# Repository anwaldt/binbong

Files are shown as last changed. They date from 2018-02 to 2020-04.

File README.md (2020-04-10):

# BinBong technical repository

## Overview

BingBong is a controller interface for the GLOOO Digital Music Instrument (DMI).
This repository contains all the necessary files to develop the firmaware for the controller and the receiving software patch for Pure Data.

## Requirements

### [Arduino IDE](https://www.arduino.cc/en/Main/Software)
  
- **Install through board manager**
  - [Redbear DUO Board package](https://github.com/redbear/Duo/blob/master/docs/arduino_board_package_installation_guide.md) 
    - **Important!** select version **0.3.1** when installing!

- **Install through library manager**
  -  Adafruit BNO055 library **1.1.9**
  -  Adafruit unified sensor library **1.0.3**
  -  Adafruit ADS1015 AD conversion library **1.0.0**
  -  AgileWare CircularBuffer **1.3.1**

- **Install manually**
  - Particle_osc (included in repo)
    - `cp /Arduino Libraries/particle_osc ${YOUR_ARDUINO_HOME}/libraries`

### [Pure Data (vanilla)](https://puredata.info/downloads)
  
- **Install through package manager inside PD** 
  - MrPeach

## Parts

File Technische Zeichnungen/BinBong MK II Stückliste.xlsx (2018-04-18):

BinBong MK II Stückliste
Part Name | Anzahl | Produkt verfügbar in/ auf |  | Verfügbar | Bemerkungen
Main Circuit
Main Circuit PCB | 1 | Lötlabor (http://www.loetlabor.org/Hauptseite) | or | 0
 |  | Beuth Hochschule (http://labor.beuth-hochschule.de/fvm/fertigung/leiterplatten-herstellung/)
RedBear Duo Microcontroller | 1 | https://www.exp-tech.de/plattformen/arm/stmicroelectronics/6995/redbear-duo-iot-board-mit-wifi-und-ble |  | 0
Force-Sesning Linear Potentiometer: 100mm x 10 mmStrip FSLP Sensor | 1 | https://www.exp-tech.de/sensoren/druck/7195/force-sensing-linear-potentiometer-100mm-x-10mm-strip-fslp-sensor |  | 0
Force-Sensing Resistor: 1.5cm-Diameter Circle, Short Tail FSR 402 Short | 4 | https://www.exp-tech.de/sensoren/druck/7198/force-sensing-resistor-1.5cm-diameter-circle-short-tail-fsr-402-short |  | 0
10 k Ohm Ceramic Resistors | 4 | Raum EN 111 |  | -
4.6 k Ohm Ceramic Resistor | 1 | Raum EN 111 |  | -
24 Ohm Ceramic Resistor | 1 | Raum EN 111 |  | -
Schraubklemmblock 0.82 mm² Polzahl 2 DG308-2.54-02P-14-00AH Degson Grün | 1 | https://www.conrad.de/de/schraubklemmblock-082-mm-polzahl-2-dg308-254-02p-14-00ah-degson-gruen-1-st-1327242.html |  | 8
Abstandshalter Polyamid Abstandsmaß 2.2 mm KSS MMS2 | 4 | https://www.conrad.de/de/abstandshalter-polyamid-abstandsmass-22-mm-kss-mms2-1-st-532152.html |  | 7
Female Pin Header Straight 12 Pol | 2 | https://www.conrad.de/de/buchsenleiste-praezision-anzahl-reihen-1-polzahl-je-reihe-36-w-p-products-153-036-1-50-10-1-st-736427.html |  | ca. 45 Pole
Female Pin Header Straight 4 Pol | 1 | https://www.conrad.de/de/buchsenleiste-praezision-anzahl-reihen-1-polzahl-je-reihe-36-w-p-products-153-036-1-50-10-1-st-736427.html |  | ca. 45 Pole
Female Pin Header Straight 3 Pol | 1 | https://www.conrad.de/de/buchsenleiste-praezision-anzahl-reihen-1-polzahl-je-reihe-36-w-p-products-153-036-1-50-10-1-st-736427.html |  | ca. 45 Pole
Female Pin Header 90° 3 Pol | 1 | https://www.conrad.de/de/buchsenleiste-praezision-anzahl-reihen-1-polzahl-je-reihe-40-w-p-products-154-040-1-50-00-1-st-739046.html |  | ca. 5 Pole
Female Pin Header 90° 8 Pol | 1 | https://www.conrad.de/de/buchsenleiste-praezision-anzahl-reihen-1-polzahl-je-reihe-40-w-p-products-154-040-1-50-00-1-st-739046.html |  | ca. 5 Pole
Sub-Circuit
Sub-Circuit PCB | 1 | Lötlabor (http://www.loetlabor.org/Hauptseite) | or | 4
 |  | Beuth Hochschule (http://labor.beuth-hochschule.de/fvm/fertigung/leiterplatten-herstellung/)
Round Force-Sensitive Resistor FSR 402 | 4 | https://www.exp-tech.de/sensoren/druck/5746/round-force-sensitive-resistor-fsr-402 |  | 3
Adafruit ADS1015 12-Bit ADC - 4 Channel with Progrmmable Gain Amplifier | 1 | https://www.exp-tech.de/module/sonstige/4579/adafruit-ads1015-12-bit-adc-4-channel-with-progrmmable-gain-amplifier |  | 2
Adafruit FLORA 9-DOF Accelerometer/ Gyroscope/ Magnetometer - LSM9DS0 | 1 | https://www.exp-tech.de/plattformen/plattformen/adafruit-flora/5835/adafruit-flora-9-dof-accelerometer/gyroscope/magnetometer-lsm9ds0 |  | 1
10 k Ohm Ceramic Resistors | 4 | Raum EN 111 |  | -
Abstandshalter Polyamid Abstandsmaß 2.2 mm KSS MMS2 | 4 | https://www.conrad.de/de/abstandshalter-polyamid-abstandsmass-22-mm-kss-mms2-1-st-532152.html |  | 7
Female Pin Header Straight 10 Pol | 1 | https://www.conrad.de/de/buchsenleiste-praezision-anzahl-reihen-1-polzahl-je-reihe-36-w-p-products-153-036-1-50-10-1-st-736427.html |  | ca. 45 Pole
Female Pin Header Straight 1 Pol | 4 | https://www.conrad.de/de/buchsenleiste-praezision-anzahl-reihen-1-polzahl-je-reihe-36-w-p-products-153-036-1-50-10-1-st-736427.html |  | ca. 45 Pole
Female Pin Header 90° 6 Pol | 1 | https://www.conrad.de/de/buchsenleiste-praezision-anzahl-reihen-1-polzahl-je-reihe-40-w-p-products-154-040-1-50-00-1-st-739046.html |  | ca. 5 Pole
Female Pin Header 90° 4 Pol | 1 | https://www.conrad.de/de/buchsenleiste-praezision-anzahl-reihen-1-polzahl-je-reihe-40-w-p-products-154-040-1-50-00-1-st-739046.html |  | ca. 5 Pole
Miscellaneous
Powerbank VOLTCRAFT PB-14 Li-Ion 2600 mAh | 1 | https://www.conrad.de/de/powerbank-zusatzakku-voltcraft-pb-14-li-ion-2600-mah-1313696.html |  | 0(+1) | Möglich, dass Thomas Lerch noch diese Teile besitzt
USB 2.0 Kabel 90° 25cm High Speed A-Stecker auf Micro-B-Winkelstecker | 1 | https://www.amazon.de/gp/product/B01ARQF3HQ/ref=oh_aui_detailpage_o01_s00?ie=UTF8&psc=1 |  | 1
Fix-o-moll Klettkabelbinder | 2 | https://www.bauhaus.info/filzgleiter-klettbaender-abdeckkappen/fix-o-moll-klettkabelbinder/p/10466606?q=klett |  | 2(+2) | Möglich, dass Thomas Lerch noch diese Teile besitzt
Stabilit Eisengewindeöse M3, L: 20 mm | 4 | https://www.bauhaus.info/ringschrauben-schraubhaken/stabilit-eisengewindeoese/p/10771377?q=ringschrauben |  | 2
Stabilit Zugfeder D: 5 mm, L: 17 mm | 1 | https://www.bauhaus.info/federn/stabilit-zugfeder/p/10772156?q=zugfeder |  | 5 | Nicht sicher, ob das der richtige Link ist, da die Federn einzeln als Kilo-Ware verkauft werden
kleine Ringschrauben | 1 |  |  | 8 | Es gibt keinen Link, wurde mir in der Kunstabteilung geschenkt
Mini Schiebeschlater | 1 |  |  | 1 | Produkt nicht mehr bei Conrad verf[gbar anscheinend

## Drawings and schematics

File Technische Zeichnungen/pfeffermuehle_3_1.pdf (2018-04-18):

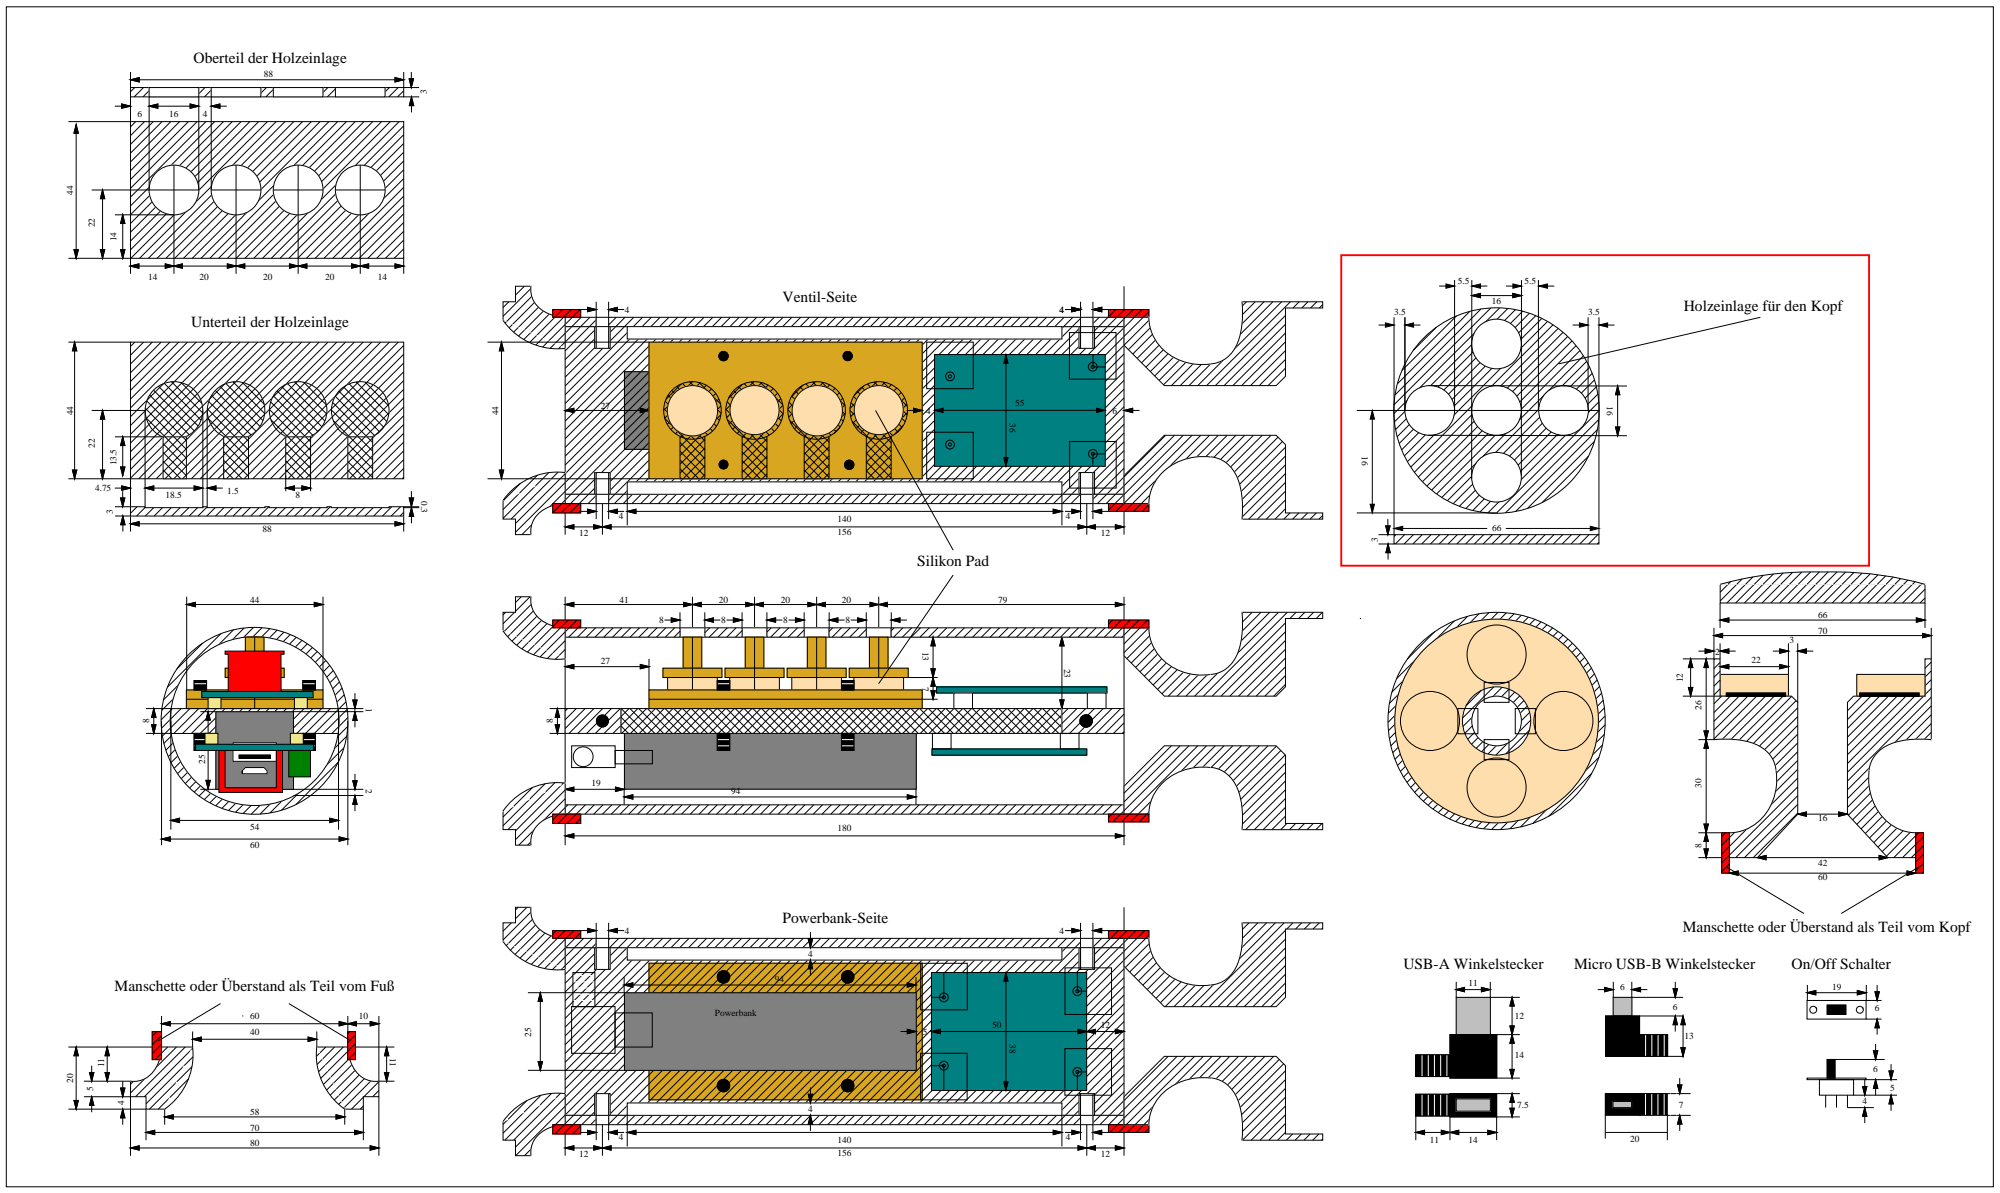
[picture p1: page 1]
Powerbank; USB-A Winkelstecker; Ventil-Seite; Powerbank-Seite; Silikon Pad

Oberteil der Holzeinlage

Holzeinlage für den Kopf

Unterteil der Holzeinlage

Manschette oder Überstand als Teil vom Kopf

Micro USB-B Winkelstecker

On/Off Schalter

Manschette oder Überstand als Teil vom Fuß

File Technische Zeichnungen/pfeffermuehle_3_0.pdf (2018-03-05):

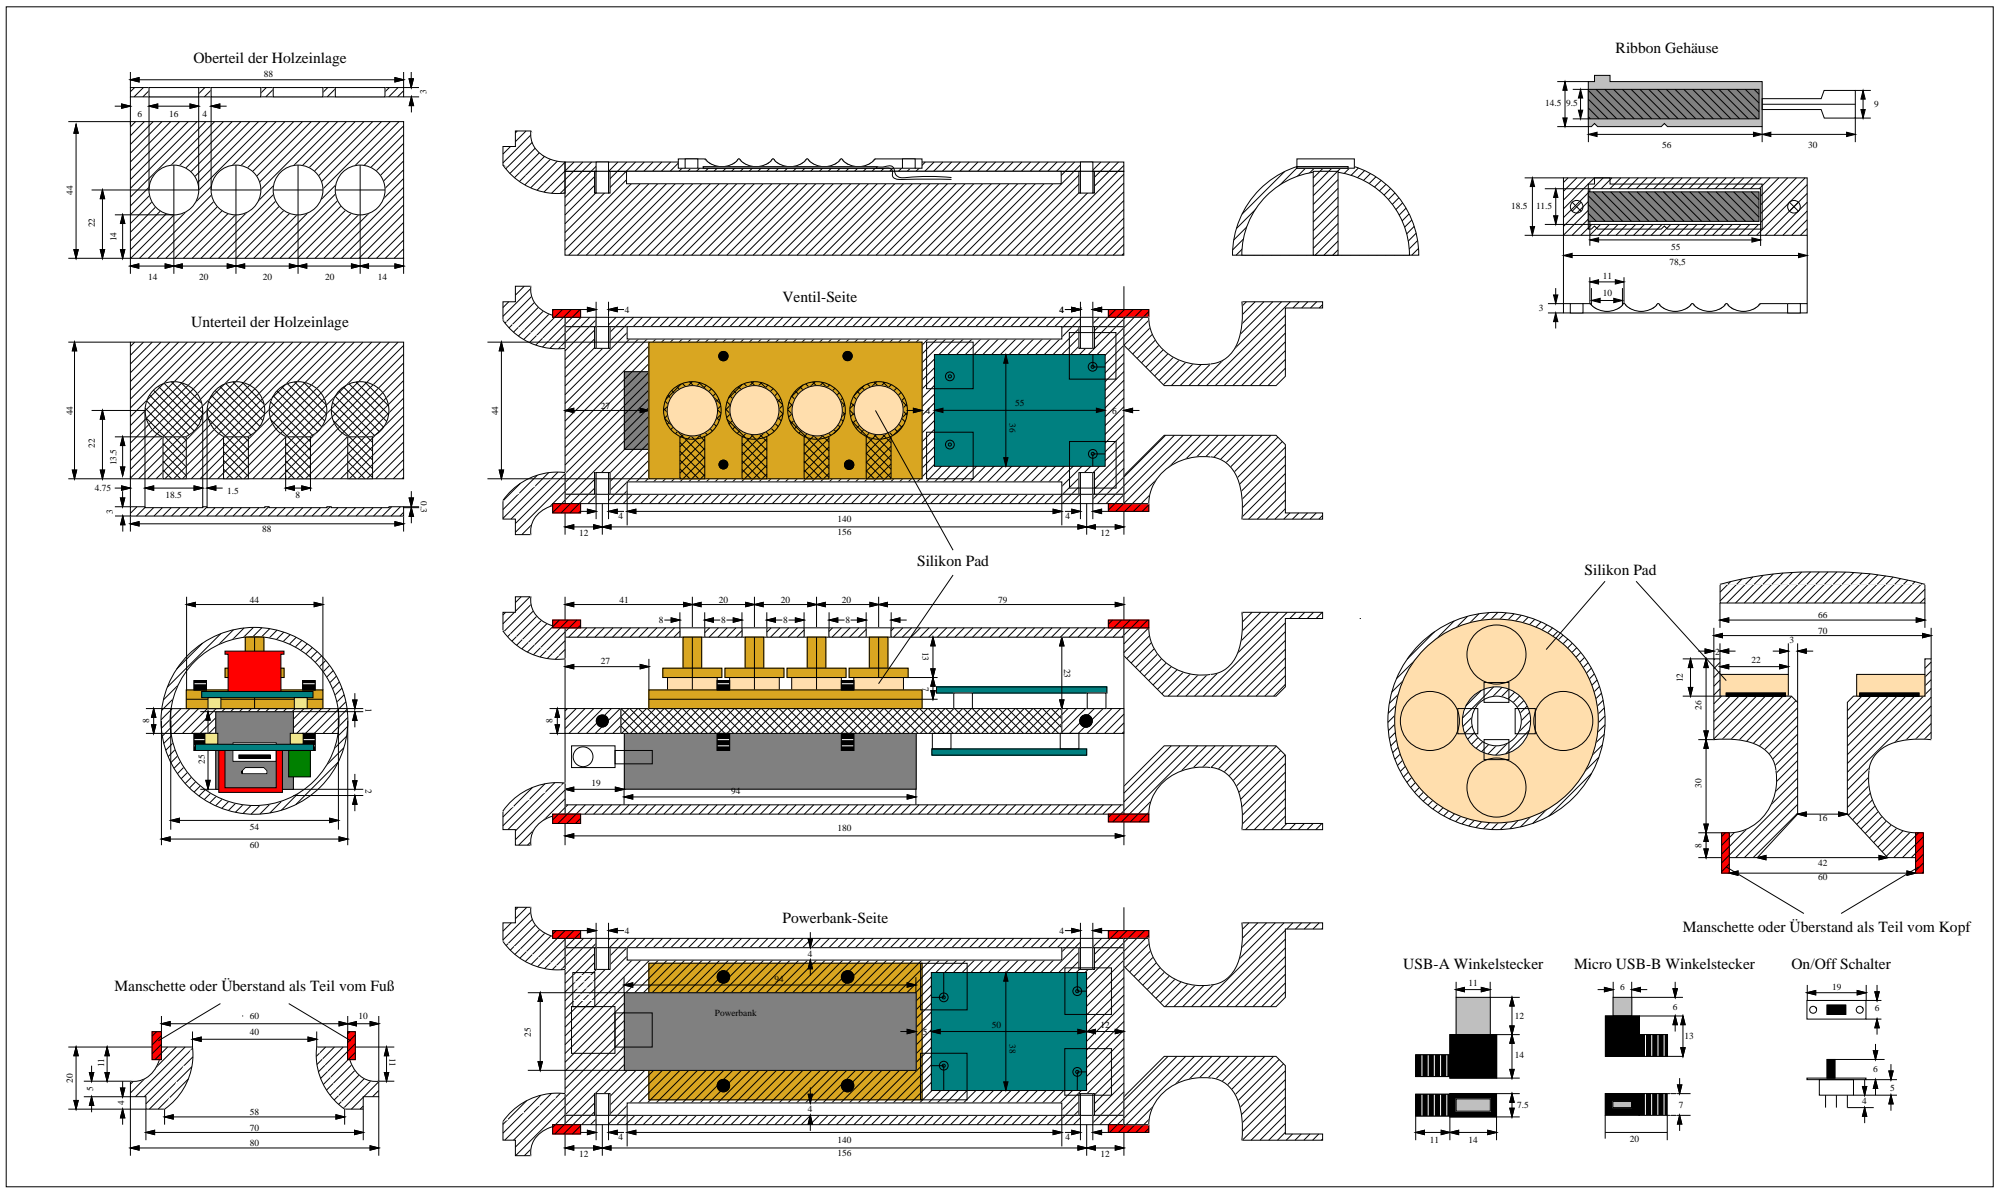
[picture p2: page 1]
Powerbank; USB-A Winkelstecker; Ventil-Seite; Powerbank-Seite; Ribbon Gehäuse

Oberteil der Holzeinlage

Unterteil der Holzeinlage

Silikon Pad

Manschette oder Überstand als Teil vom Kopf

Micro USB-B Winkelstecker

On/Off Schalter

Manschette oder Überstand als Teil vom Fuß

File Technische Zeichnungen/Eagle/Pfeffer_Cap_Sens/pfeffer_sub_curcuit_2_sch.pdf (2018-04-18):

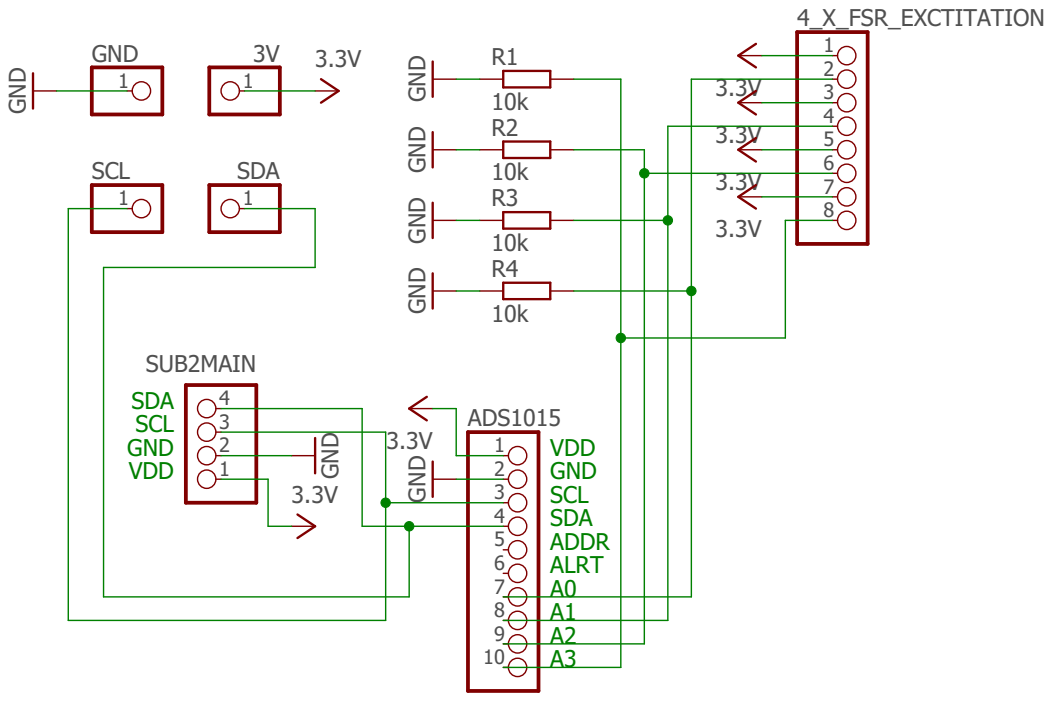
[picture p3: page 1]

GND GND GND GND GNGND D 3.3V 3.3V 3.3V 3.3V 3.3V 10k 10k 10k 10k 3.3V 3.3V GND ADS1015 12345678910 4_X_FSR_EXCTITATION 12345678 R1R2R3R4 GND1 3V 1 SCL1 SDA 1 1234 SUB2MAIN VDD GND SCL SDA ADDR ALRT A0A1A2A3 VDD GND SCL SDA

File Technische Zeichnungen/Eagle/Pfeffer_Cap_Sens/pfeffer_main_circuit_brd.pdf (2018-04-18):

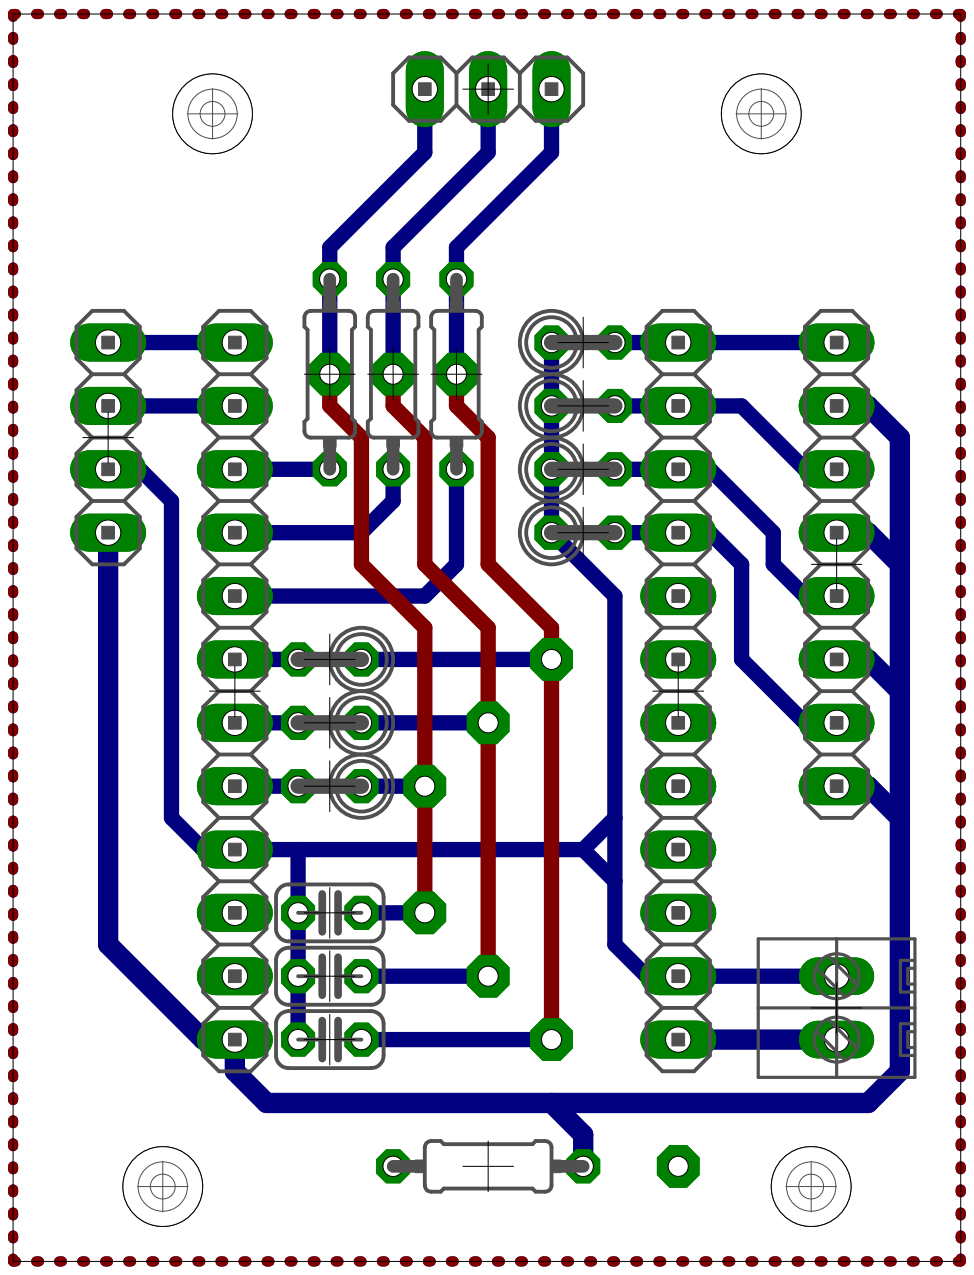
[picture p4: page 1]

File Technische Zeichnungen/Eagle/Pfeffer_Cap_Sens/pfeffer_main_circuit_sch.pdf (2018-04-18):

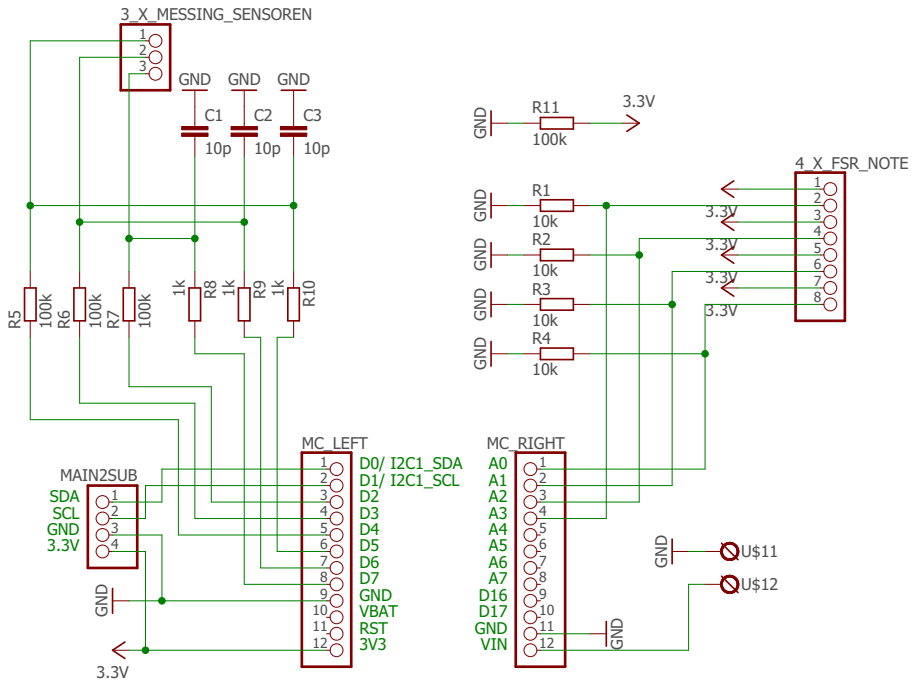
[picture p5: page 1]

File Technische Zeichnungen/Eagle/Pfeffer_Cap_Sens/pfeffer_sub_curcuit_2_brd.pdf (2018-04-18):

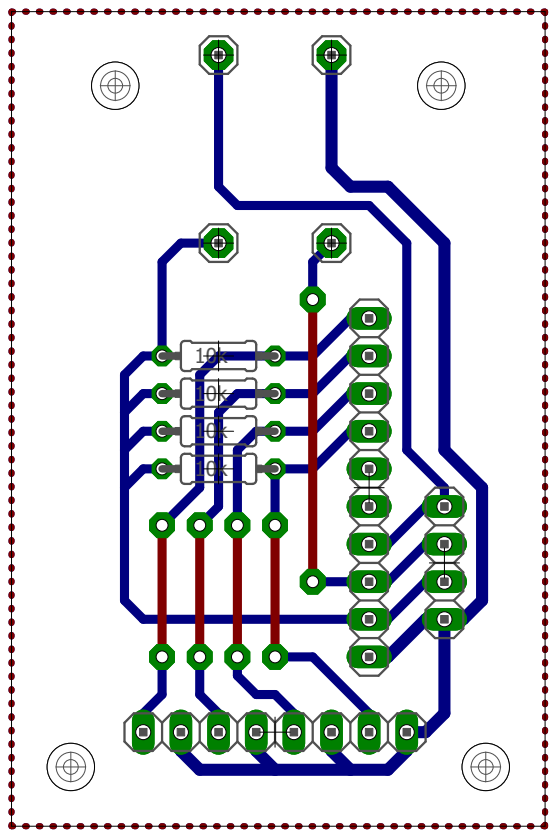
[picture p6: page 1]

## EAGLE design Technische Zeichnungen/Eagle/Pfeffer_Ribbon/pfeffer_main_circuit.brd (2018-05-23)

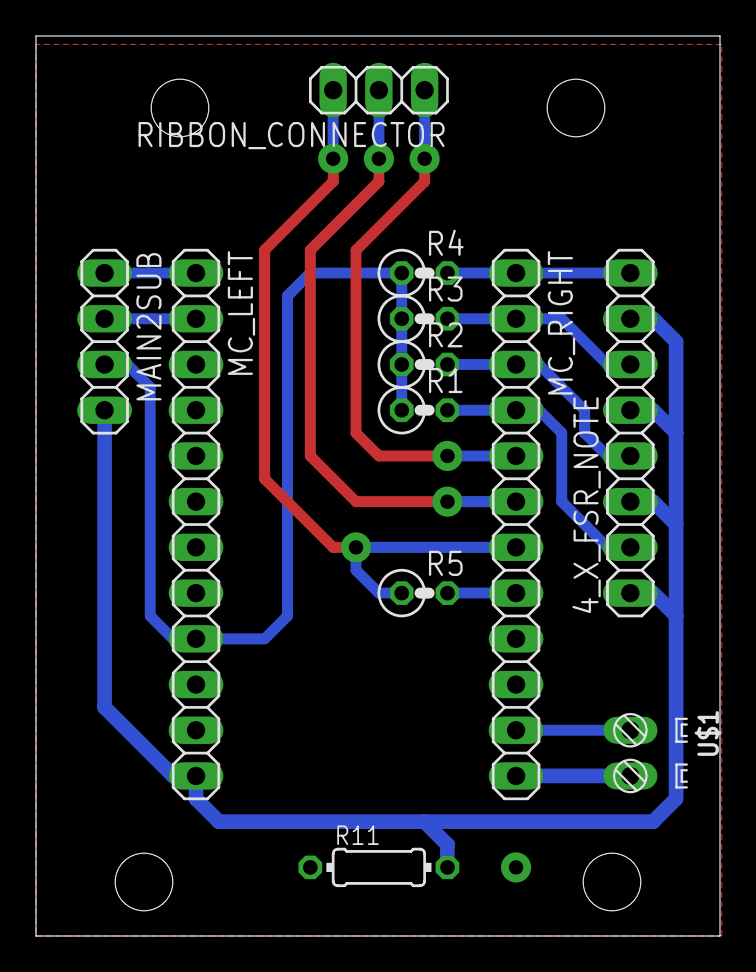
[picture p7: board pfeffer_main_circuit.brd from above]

Board: 2 copper layers, 38.0 x 50.0 mm, 12 parts (0 on the bottom side), 14 nets.

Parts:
4_X_FSR_NOTE: 1X08
MAIN2SUB: 1X04
MC_LEFT: 1X12
MC_RIGHT: 1X12
R1, R2, R3, R4: 10k; 0207/2V
R5: 4.6k; 0207/2V
R11: 24; 0204/7
RIBBON_CONNECTOR: 1X03
U$1: DS308-02; DS308-2.54-02P

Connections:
GND: MAIN2SUB.3, MC_LEFT.9, R1.1, R2.1, R3.1, R4.1, R11.1
unnamed: 4_X_FSR_NOTE.2, MC_RIGHT.4, R1.2
unnamed: 4_X_FSR_NOTE.4, MC_RIGHT.3, R2.2
unnamed: 4_X_FSR_NOTE.6, MC_RIGHT.2, R3.2
unnamed: 4_X_FSR_NOTE.8, MC_RIGHT.1, R4.2
unnamed: MC_RIGHT.12, U$1.2
unnamed: MAIN2SUB.1, MC_LEFT.1
unnamed: MC_RIGHT.5, RIBBON_CONNECTOR.1
unnamed: MC_RIGHT.6, RIBBON_CONNECTOR.2
unnamed: MC_RIGHT.7, R5.1, RIBBON_CONNECTOR.3
unnamed: MC_RIGHT.8, R5.2
unnamed: MC_RIGHT.11, U$1.1
unnamed: MAIN2SUB.2, MC_LEFT.2
VCC: 4_X_FSR_NOTE.1, 4_X_FSR_NOTE.3, 4_X_FSR_NOTE.5, 4_X_FSR_NOTE.7, MAIN2SUB.4, MC_LEFT.12, R11.2

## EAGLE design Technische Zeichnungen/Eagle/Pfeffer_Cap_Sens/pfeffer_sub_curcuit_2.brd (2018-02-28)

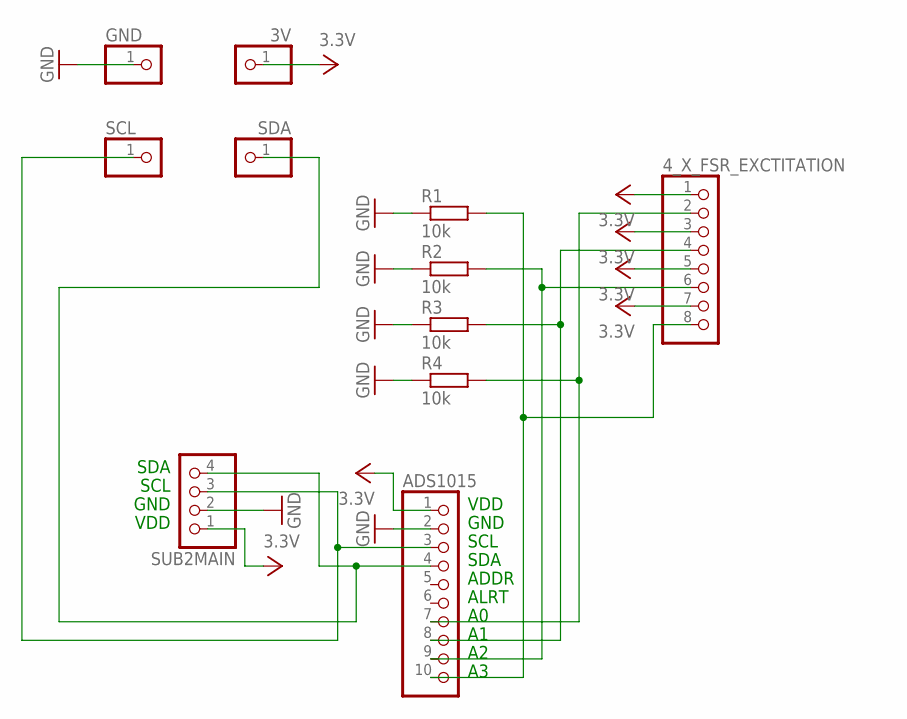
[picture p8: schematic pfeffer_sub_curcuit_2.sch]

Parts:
3V: PINHD-1X1; 1X01
4_X_FSR_EXCTITATION: PINHD-1X8; 1X08
ADS1015: PINHD-1X10; 1X10
GND: PINHD-1X1; 1X01
R1, R2, R3, R4: 10k; 0204/7
SCL: PINHD-1X1; 1X01
SDA: PINHD-1X1; 1X01
SUB2MAIN: PINHD-1X4; 1X04

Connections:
GND: ADS1015.2, GND.1, R1.1, R2.1, R3.1, R4.1, SUB2MAIN.2
unnamed: 4_X_FSR_EXCTITATION.8, ADS1015.10, R1.2
unnamed: 4_X_FSR_EXCTITATION.6, ADS1015.9, R2.2
unnamed: ADS1015.3, SCL.1, SUB2MAIN.3
unnamed: ADS1015.4, SDA.1, SUB2MAIN.4
unnamed: 4_X_FSR_EXCTITATION.4, ADS1015.8, R3.2
unnamed: 4_X_FSR_EXCTITATION.2, ADS1015.7, R4.2
VCC: 3V.1, 4_X_FSR_EXCTITATION.1, 4_X_FSR_EXCTITATION.3, 4_X_FSR_EXCTITATION.5, 4_X_FSR_EXCTITATION.7, ADS1015.1, SUB2MAIN.1

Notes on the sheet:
VDD
GND
SCL
SDA
ADDR
ALRT

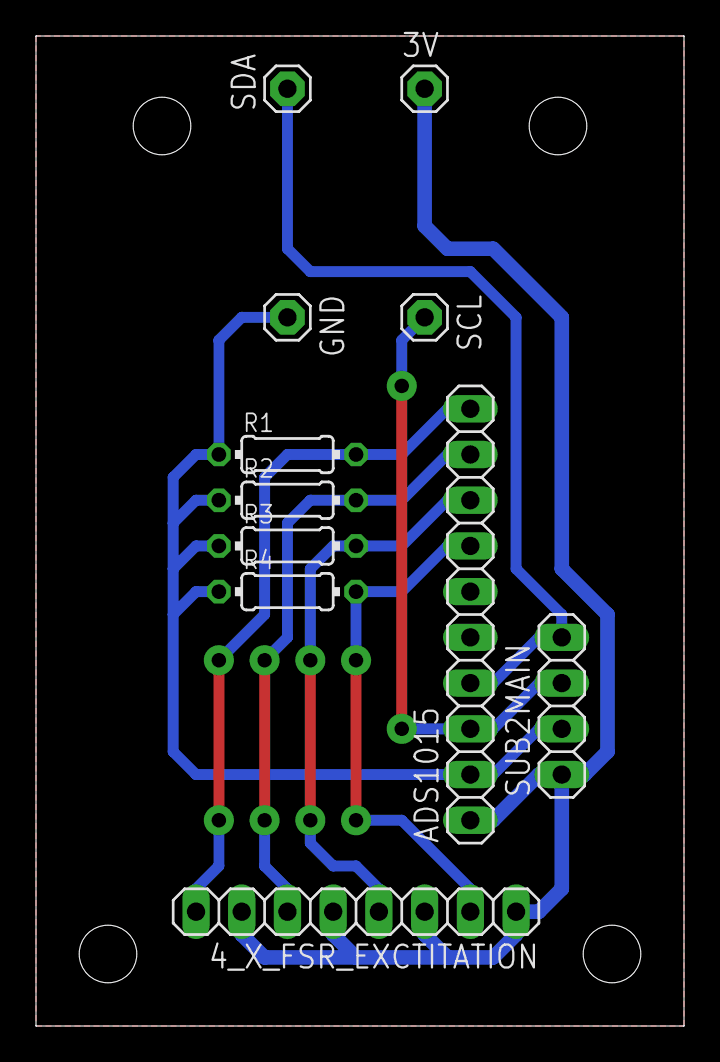
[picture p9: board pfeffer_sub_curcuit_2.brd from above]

Board: 2 copper layers, 36.0 x 55.0 mm, 11 parts (0 on the bottom side), 8 nets.

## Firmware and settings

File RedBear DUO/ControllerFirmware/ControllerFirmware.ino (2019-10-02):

/*

  Authors: Henrik von Coler, Anton Schmied, Yrkkö Äkkijyrkkä
  Date: 2019-06-10

*/

#if defined(ARDUINO)
SYSTEM_MODE(SEMI_AUTOMATIC);
#endif

/************************************************************************************************************
   libraries
 ************************************************************************************************************/

#include "util.h"
#include "imu.h"
#include "valves.h"
#include "pad.h"
#include "ribbon.h"

/************************************************************************************************************
   variables

 ************************************************************************************************************/

//float const PI_F = 3.14159265F;

/************************************************************************************************************
  Setup Function for Wifi Connection and Module Initialization
************************************************************************************************************/
void setup()
{
  Serial.begin(9600);
  /****************************************** Establish WiFi Connection *************************************/
  setupWifi();
  delay(1000);
  /******************************************* Establish UDP Connection *************************************/
  udpConnection.begin(LOCALPORT);
  /**************************************** Initialize ads1015 and bno055 **********************************/
  delay(1000);
  /* Initialise the sensor */
  setup_bno();
  delay(1000);
  /**************************************** calibrate modules **********************************/
  calibrate_pad();
  delay(1000);
  calibrate_valves();
}

/************************************************************************************************************
   Main Loop Function
 ************************************************************************************************************/
void loop()
{
  msg = "/id/" + IP;
  msg.toCharArray(copy, 50);
  fsr_bndl.add(copy).add(deviceID);

  // Prepare all data
  prepare_ribbon_data();
  prepare_valve_data();
  prepare_pad_data();
  prepare_imu_data();

  // Send data
  send_bundle();
}

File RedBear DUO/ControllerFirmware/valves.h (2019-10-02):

const int valveMAX = 4000;

int pressureSum       = 0; //!< ACID
int valve_offset[4]   = {0, 0, 0, 0};
int noteCurrentMillis = 0;
int noteDiffMillis    = 0;
int holdPitch         = 0;

void calibrate_valves()
{
    valve_offset[0] = analogRead(A3);
    valve_offset[1] = analogRead(A2);
    valve_offset[2] = analogRead(A1);
    valve_offset[3] = analogRead(A0);
}

void prepare_valve_data()
{
    /********************************************** Read Pitch Sensors ****************************************/
    int fsrPressed    = 0;
    int currentPitch  = 0;
    pressureSum       = 0;

    float fsrPressure = (float)(analogRead(A3) - valve_offset[0]) / (float)(valveMAX - valve_offset[0]);
    msg = "/bong/" + IP + "/valve/1";
    msg.toCharArray(copy, 50);
    fsr_bndl.add(copy).add(fsrPressure);

    if (fsrPressure > NOTETHR)
    {
        // currentPitch |= 0x0001; // set first Bit to 1
        currentPitch += 1;
        pressureSum += (fsrPressure - NOTETHR);
        fsrPressed++;
    }

    fsrPressure = (float)(analogRead(A2) - valve_offset[1]) / (float)(valveMAX - valve_offset[1]);
    msg = "/bong/" + IP + "/valve/2";
    msg.toCharArray(copy, 50);
    fsr_bndl.add(copy).add(fsrPressure);

    if (fsrPressure > NOTETHR)
    {
        // currentPitch |= 0x0002; // set second Bit to 1
        currentPitch += 2;
        pressureSum += (fsrPressure - NOTETHR);
        fsrPressed++;
    }

    fsrPressure = (float)(analogRead(A1) - valve_offset[2]) / (float)(valveMAX - valve_offset[2]);
    msg = "/bong/" + IP + "/valve/3";
    msg.toCharArray(copy, 50);
    fsr_bndl.add(copy).add(fsrPressure);

    if (fsrPressure > NOTETHR)
    {
        // currentPitch |= 0x0004; // set third Bit to 1
        currentPitch += 4;
        pressureSum += (fsrPressure - NOTETHR);
        fsrPressed++;
    }

    fsrPressure = (float)(analogRead(A0) - valve_offset[3]) / (float)(valveMAX - valve_offset[3]);
    msg = "/bong/" + IP + "/valve/4";
    msg.toCharArray(copy, 50);
    fsr_bndl.add(copy).add(fsrPressure);

    if (fsrPressure > NOTETHR)
    {
        // currentPitch |= 0x0008; // set fourth Bit to 1    
        currentPitch += 8;
        pressureSum += (fsrPressure - NOTETHR);
        fsrPressed++;
    }

    if (currentPitch != holdPitch)
    {
        noteCurrentMillis = millis();
        noteDiffMillis = 0;
        holdPitch = currentPitch;
    }

    /***************************************** Calculate MIDI Pitch Value *************************************/
    int notePitch = 0;

    if (fsrPressed > 0)
    {
        pressureSum = pressureSum / fsrPressed;
        //pressureSum = map(pressureSum, 0, 4095-NOTETHR, 0, 1);
        //pressureSum = constrain(pressureSum, 0 ,1);

        if (noteDiffMillis > 5)
        {
            notePitch = (holdPitch);
            //Serial.print("notepitch: ");
            //Serial.println(notePitch);
        }
        else if (noteDiffMillis < 5)
        {
            noteDiffMillis = millis() - noteCurrentMillis;
        }
    }
    else
    {
        notePitch = 0;
        pressureSum = 0;
        holdPitch = 0;
    }

    float intensity = (float)pressureSum / 900.0;

    msg = "/bong/" + IP + "/note";
    msg.toCharArray(copy, 50);
    fsr_bndl.add(copy).add(notePitch);

    msg = "/bong/" + IP + "/intensity";
    msg.toCharArray(copy, 50);
    //fsr_bndl.add(copy).add(intensity);
}

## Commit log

2018-02-28 added pcb layouts (eagle)
    [pfeffer_main_circuit.brd, pfeffer_main_circuit.sch, pfeffer_sub_curcuit_2.brd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]
2018-02-28 updated ribbon pcb layout
2018-03-05 updated PCBs and the technical Drawing
    [pfeffer_main_circuit.brd]
2018-04-18 added ribbon testing, firmware and applied it to the new firmware, added a new tech. drawing, added new PCB layouts
    [pfeffer_main_circuit.brd, pfeffer_main_circuit.sch, pfeffer_sub_curcuit_2.sch]
2018-04-18 added BinBong Partslist
    [BinBong MK II Stückliste.xlsx]
2018-05-23 little but significant changes to the schemtaics and circuit
    [pfeffer_main_circuit.brd]
2018-05-23 added further Arduino Libraries
    [bunny.obj]
2018-11-04 Sending two bundles (FSR,IMU) - PD patch showing all sensors! (but temperature ...)
2018-11-08 Added calibration for the FSRs at startup! (by subtracting the pressure when unpressed)
2018-11-29 Decreased valve threshold to 150!
2019-01-13 Improved scaling for valve sensors!
2019-01-22 Sensor fusion now in main patch!
2019-07-02 Switched to WiFi connection to Notlandung!
2019-10-02 firmware: New version supporting the new IMU.
    Add support for the BN055 sensor fusion package.
    Provide pitch, roll and heading to OSC.
2019-10-02 puredata: minor update to received IMU values
    change scaling of values according to the ones provided by BN055
2019-10-02 firmware: Working version with BNO055 and new power circuit.
    Refactor display functions. Send calibration status data to puredata.
2019-10-02 firmware: quick fix.
    Change to correct wifi network. Add forgotten pad function, was not
    working.
    [ribbon.h]
2019-10-02 firmware: changed valve sensor processing from bitmask to integer mode
2019-10-16 firmware: Updated ip address of the gateway.
    Changed ip address due to firmware update on the gateway.
    Minor cleanup of various print messages.
2019-11-06 firmware: Revert credentials, add documentation.
    Reverted to using the fritzbox due to reliability issues with the
    tp-link device.
    Added documentation on how to do fres install of the development environment.
2019-11-20 firmware: Enable swipe gesture for octave change.
    Collect finger position delta values in a buffer and sum them to detect
    swiping gestures.
    This is much more convenient than the old way of having static mapping
    of the ribbon as octave zones. Old position information is not
    conflicting and can be used for some other mapping if needed.
2019-11-20 firmware: Delete vendored libraries.
    Remove static libraries as they can all installed much easier from
    arduino library manager and this ensures that the compiler finds them
    by default if the user is using arduino IDE.
    [bunny.obj]
